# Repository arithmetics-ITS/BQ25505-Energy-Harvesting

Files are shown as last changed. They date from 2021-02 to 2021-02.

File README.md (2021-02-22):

# Breakout Board: BQ25505 ultra low-power energy harvester with battery management and autonomous power multiplexing
## Description

The bq25505 device is specifically designed to efficiently extract the microwatts (μW) to miliwatts (mW) of power generated from a variety of DC energy harvesting, high-impedance sources like photovoltaic (solar) or thermal electric generators (TEGs) without collapsing those sources. The batterymanagement features of the bq25505 ensure that a secondary rechargeable battery is not overcharged by this extracted power, with voltage boosted, nor depleted beyond safe limits by a system load. The
integrated multiplexer gate drivers autonomously switch the system load to a primary nonrechargeable battery if the secondary battery voltage falls below the user-defined VBAT_OK threshold.

## Features

- Texas Instruments BQ25505
- Designed for solar applications with MPPT
- 2x Dual, P-Channel, ChipFET 20 V, 4.1 A for primary and secondary battery switching
- 2x LEDs to visualize the currently used battery (PRI or SEC)

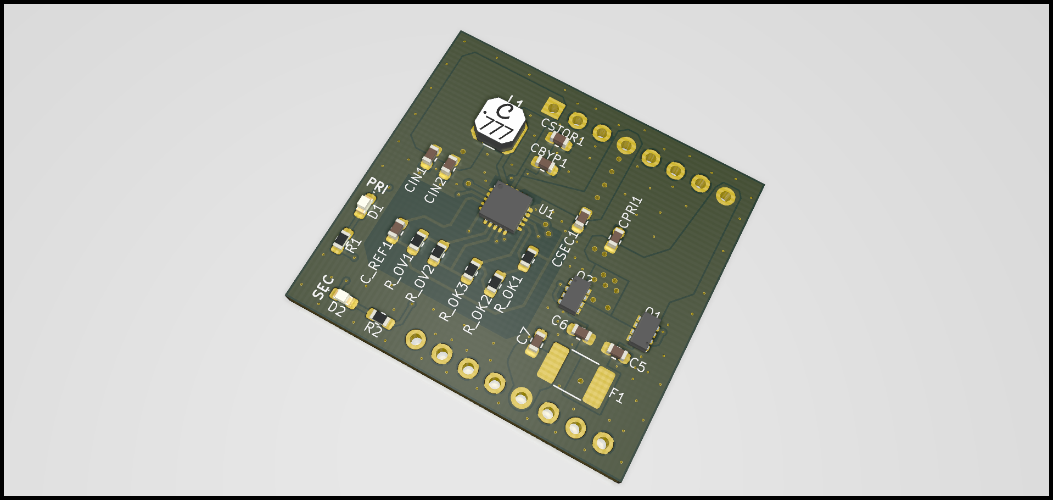
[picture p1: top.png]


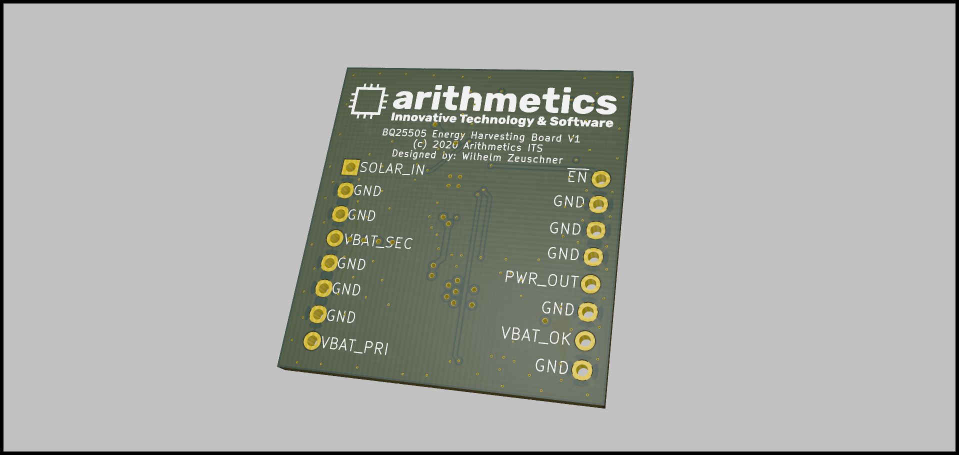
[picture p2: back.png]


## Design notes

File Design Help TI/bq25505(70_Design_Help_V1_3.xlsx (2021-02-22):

User Input | VBIAS | 1.21 | V
Fixed
 | Comparator threshold for VSTOR of charger. |  |  |  |  | Comparator threshold voltages indicating when |  |  |  |  | For the bq25570 only, comparator threshold |  |  |  |  | Maximum power point threshold, e.g. ~0.7-0.8 of
 | Typically the max storage element voltage, |  |  |  |  | VSTOR has risen above VBAT_OK_HYST or fallen |  |  |  |  | for VOUT of buck converter. |  |  |  |  | solar panel's open circuit voltage.
 | e.g. 4.2V for LiIon battery. |  |  |  |  | below VBAT_OK.
 | VBAT_UV < VBAT_OV < 5.5V |  |  |  |  | VBAT_OV > VBAT_OK_HYST > VBAT_UV |  |  |  |  | 1.3V < VOUT < VBAT_OV |  |  |  |  | MPPT
Desired |  |  |  |  |  | RSUM1 | 13 | MW |  |  |  |  |  |  |  | RSUM1 | 20 | MW
Desired | RSUM1 | 13 | MW |  |  | VBAT_OK | 2.8 | V | > VBAT_UV |  | RSUM1 | 13 | MW |  |  | VIN_DC(OC) | 1 | V | Open Circuit Volts
Desired | VBAT_OV | 4.2 | V |  |  | VBAT_OK_HYST | 3.1 | V | > VBAT_OK |  | VOUT | 1.3 | V |  |  | VREF_SAMP | 0.9 | V | MPP voltage
 |  |  |  |  |  |  |  | closest 1% resistor1 |  |  |  |  |  |  |  |  |  | closest 1% resistor1
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

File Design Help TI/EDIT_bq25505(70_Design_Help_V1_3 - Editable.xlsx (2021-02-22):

User Input | VBIAS | 1.21 | V |  |  |  |  |  |  |  | NICHT VERWENDET / BENÖTIGT |  |  |  |  | NICHT VERWENDET / BENÖTIGT
Fixed
 | Comparator threshold for VSTOR of charger. |  |  |  |  | Comparator threshold voltages indicating when |  |  |  |  | For the bq25570 only, comparator threshold |  |  |  |  | Maximum power point threshold, e.g. ~0.7-0.8 of
 | Typically the max storage element voltage, |  |  |  |  | VSTOR has risen above VBAT_OK_HYST or fallen |  |  |  |  | for VOUT of buck converter. |  |  |  |  | solar panel's open circuit voltage.
 | e.g. 4.2V for LiIon battery. |  |  |  |  | below VBAT_OK.
 | VBAT_UV < VBAT_OV < 5.5V |  |  |  |  | VBAT_OV > VBAT_OK_HYST > VBAT_UV |  |  |  |  | 1.3V < VOUT < VBAT_OV |  |  |  |  | MPPT
Desired |  |  |  |  |  | RSUM1 | 13 | MW |  |  |  |  |  |  |  | RSUM1 | 20 | MW
Desired | RSUM1 | 14 | MW |  |  | VBAT_OK | 2.5 | V | > VBAT_UV |  | RSUM1 | 13 | MW |  |  | VIN_DC(OC) | 1 | V | Open Circuit Volts
Desired | VBAT_OV | 4.1 | V |  |  | VBAT_OK_HYST | 2.7 | V | > VBAT_OK |  | VOUT | 1.3 | V |  |  | VREF_SAMP | 0.9 | V | MPP voltage
 |  |  |  |  |  |  |  | closest 1% resistor1 |  |  |  |  |  |  |  |  |  | closest 1% resistor1
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

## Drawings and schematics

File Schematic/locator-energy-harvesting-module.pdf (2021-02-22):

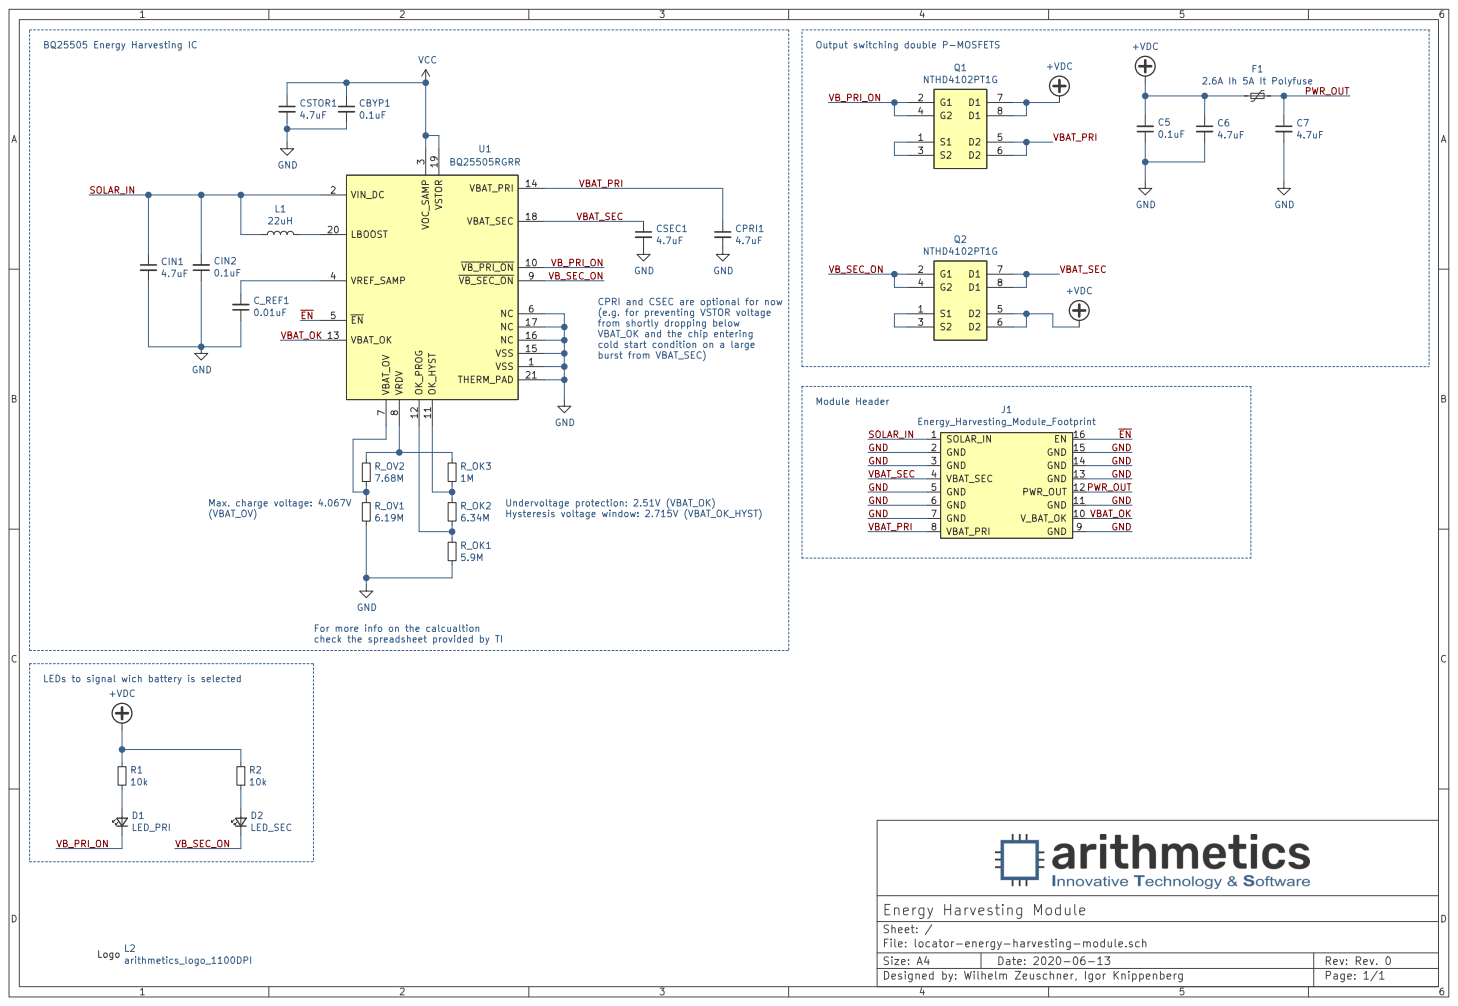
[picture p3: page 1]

Output switching double P-MOSFETS

CPRI and CSEC are optional for now
(e.g. for preventing VSTOR voltage
from shortly dropping below
VBAT_OK and the chip entering
cold start condition on a large
burst from VBAT_SEC)

check the spreadsheet provided by TI

Energy Harvesting Module
File: locator-energy-harvesting-module.sch Sheet: /

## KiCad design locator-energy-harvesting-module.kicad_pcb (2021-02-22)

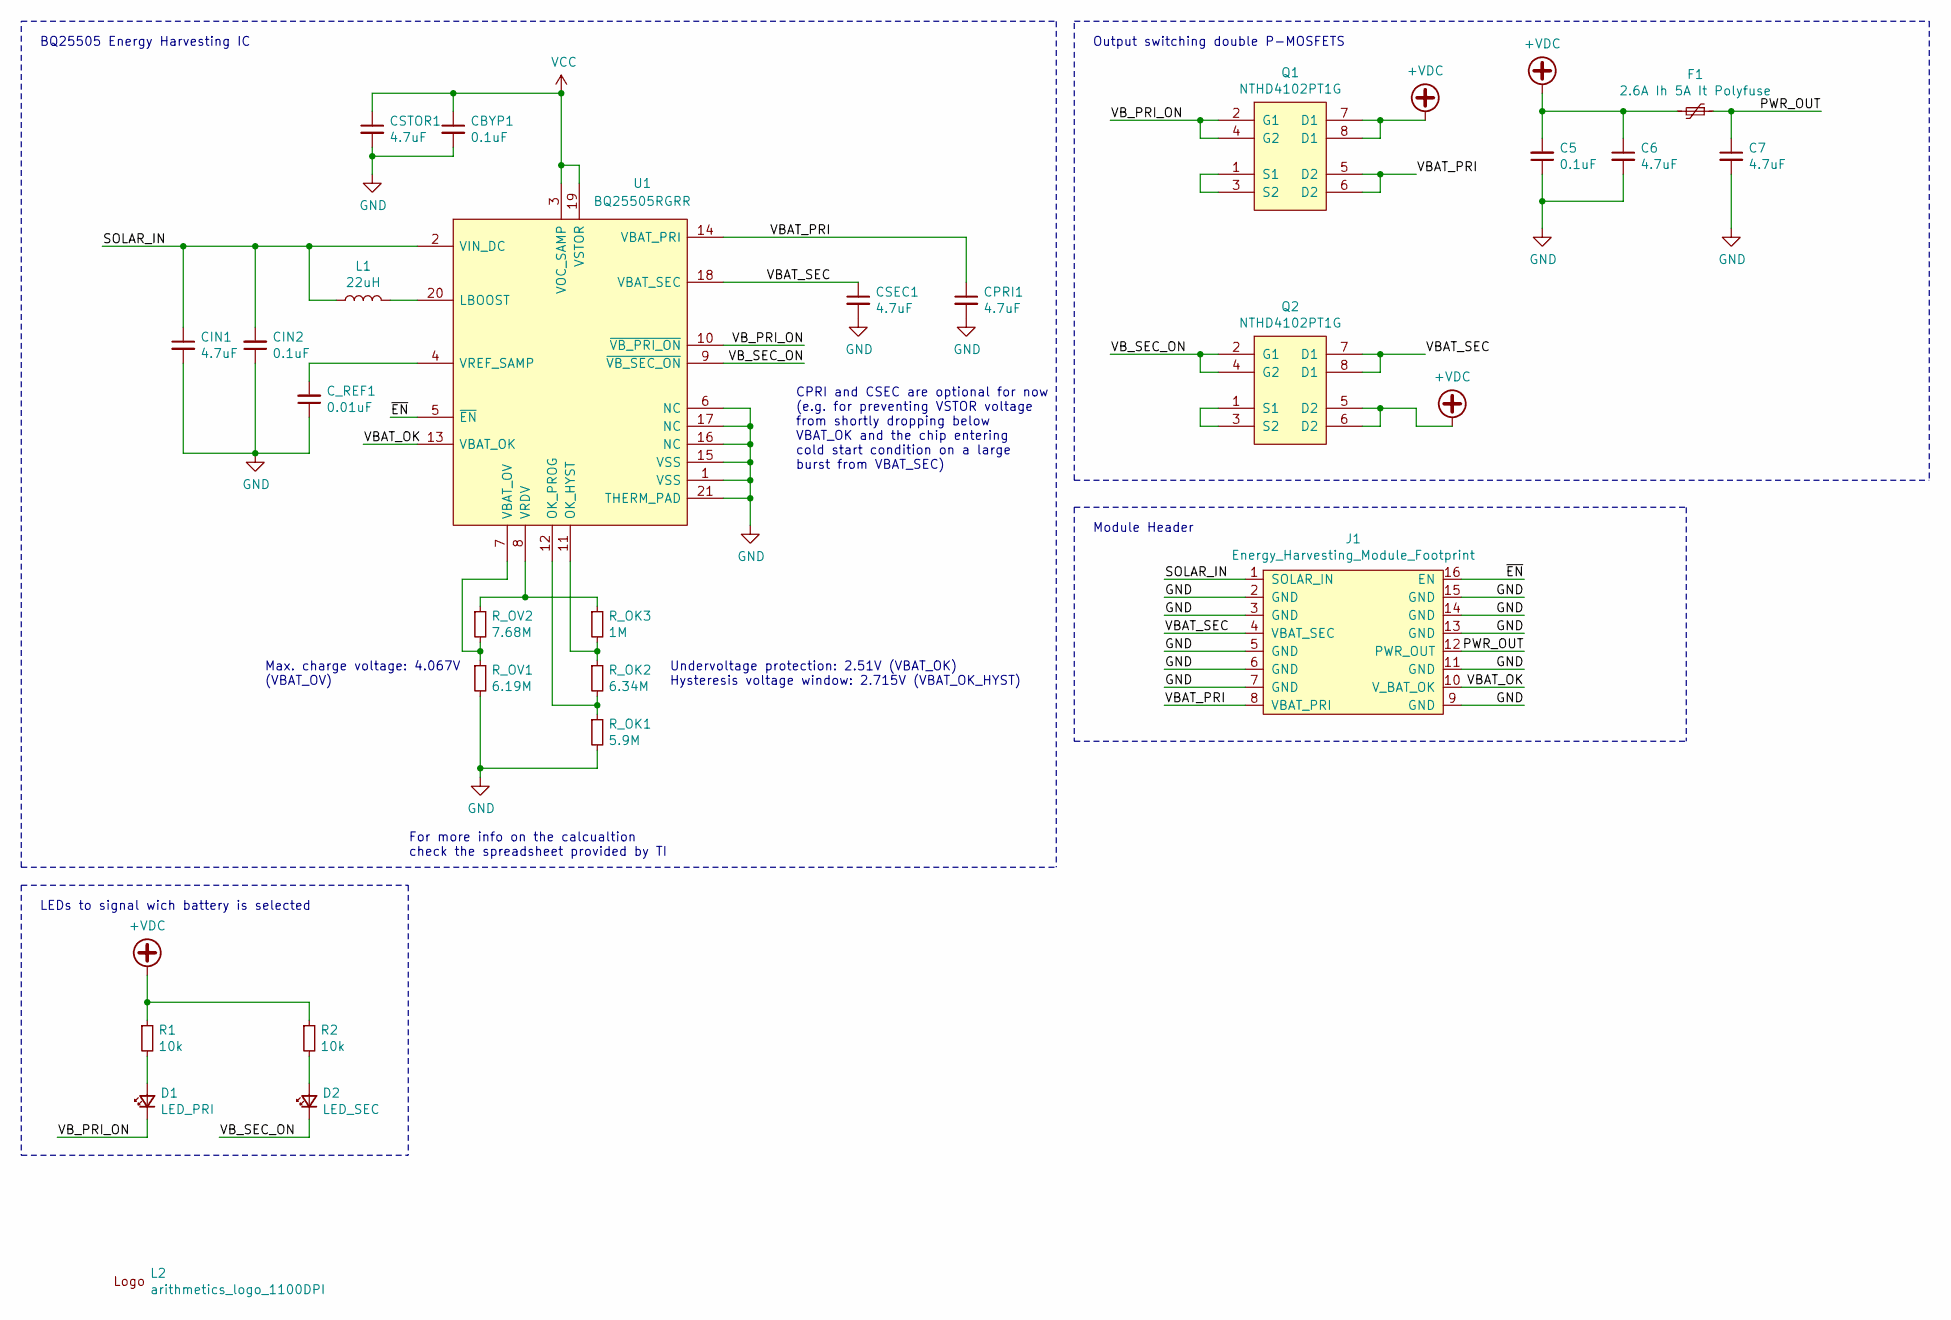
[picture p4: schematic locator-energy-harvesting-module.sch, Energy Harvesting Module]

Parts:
C5: 0.1uF; C_0603_1608Metric; MPN C0603X104J4RECAUTO
C6, C7: 4.7uF; C_0603_1608Metric; MPN C1608X5R1C475K080AC
CBYP1: 0.1uF; C_0603_1608Metric; MPN C0603X104J4RECAUTO
CIN1: 4.7uF; C_0603_1608Metric; MPN C1608X5R1C475K080AC
CIN2: 0.1uF; C_0603_1608Metric; MPN C0603X104J4RECAUTO
CPRI1: 4.7uF; C_0603_1608Metric; MPN C1608X5R1C475K080AC
CSEC1: 4.7uF; C_0603_1608Metric; MPN C1608X5R1C475K080AC
CSTOR1: 4.7uF; C_0603_1608Metric; MPN C1608X5R1C475K080AC
C_REF1: 0.01uF; C_0603_1608Metric; MPN GRM1885C1H103JA01D
D1: LED_PRI; LED_0603_1608Metric; MPN LS L29K-G1H2-1-Z
D2: LED_SEC; LED_0603_1608Metric; MPN LS L29K-G1H2-1-Z
F1: 2.6A Ih 5A It Polyfuse; Fuse_1812_4532Metric_Castellated; MPN 0ZCG0260FF2C
J1: Energy_Harvesting_Module_Footprint
L1: 22uH; L_Coilcraft_LPS4018; MPN LPS4018-223MRB
L2: arithmetics_logo_1100DPI; logo_1100_DPI
Q1, Q2: NTHD4102PT1G; NTHD4102P_ChipFET_CASE_1206A; MPN NTHD4102PT1G
R1, R2: 10k; R_0603_1608Metric; MPN AC0603JR-0710KL
R_OK1: 5.9M; R_0603_1608Metric; MPN CRCW06035M90FKEA
R_OK2: 6.34M; R_0603_1608Metric; MPN CRCW06036M34FKEA
R_OK3: 1M; R_0603_1608Metric; MPN AC0603FR-071ML
R_OV1: 6.19M; R_0603_1608Metric; MPN CRCW06036M19FKEA
R_OV2: 7.68M; R_0603_1608Metric; MPN CRCW06037M68FKEA
U1: BQ25505RGRR; BQ25505; MPN BQ25505RGRR

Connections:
+VDC: C5.2, C6.1, F1.2, Q1.7 (D1), Q1.8 (D1), Q2.5 (D2), Q2.6 (D2), R1.1, R2.1
/PWR_OUT: C7.1, F1.1, J1.12 (PWR_OUT)
/SOLAR_IN: CIN1.1, CIN2.2, J1.1 (SOLAR_IN), L1.1, U1.2 (VIN_DC)
/VBAT_OK: J1.10 (V_BAT_OK), U1.13 (VBAT_OK)
/VBAT_PRI: CPRI1.1, J1.8 (VBAT_PRI), Q1.5 (D2), Q1.6 (D2), U1.14 (VBAT_PRI)
/VBAT_SEC: CSEC1.1, J1.4 (VBAT_SEC), Q2.7 (D1), Q2.8 (D1), U1.18 (VBAT_SEC)
/VB_PRI_ON: D1.1 (K), Q1.2 (G1), Q1.4 (G2), U1.10 (~VB_PRI_ON)
/VB_SEC_ON: D2.1 (K), Q2.2 (G1), Q2.4 (G2), U1.9 (~VB_SEC_ON)
/~EN: J1.16 (EN), U1.5 (~EN)
GND: C5.1, C6.2, C7.2, CBYP1.2, CIN1.2, CIN2.1, CPRI1.2, CSEC1.2, CSTOR1.2, C_REF1.1, J1.2 (GND), J1.3 (GND), J1.5 (GND), J1.6 (GND), J1.7 (GND), J1.9 (GND), J1.11 (GND), J1.13 (GND), J1.14 (GND), J1.15 (GND), R_OK1.2, R_OV1.2, U1.1 (VSS), U1.6 (NC), U1.15 (VSS), U1.16 (NC), U1.17 (NC), U1.21 (THERM_PAD)
unnamed: C_REF1.2, U1.4 (VREF_SAMP)
unnamed: D1.2 (A), R1.2
unnamed: D2.2 (A), R2.2
unnamed: L1.2, U1.20 (LBOOST)
unnamed: Q1.1 (S1), Q1.3 (S2)
unnamed: Q2.1 (S1), Q2.3 (S2)
unnamed: R_OK1.1, R_OK2.2, U1.12 (OK_PROG)
unnamed: R_OK2.1, R_OK3.2, U1.11 (OK_HYST)
unnamed: R_OK3.1, R_OV2.1, U1.8 (VRDV)
unnamed: R_OV1.1, R_OV2.2, U1.7 (VBAT_OV)
VCC: CBYP1.1, CSTOR1.1, U1.3 (VOC_SAMP), U1.19 (VSTOR)

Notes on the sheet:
For more info on the calcualtion check the spreadsheet provided by TI
Module Header
Output switching double P-MOSFETS
BQ25505 Energy Harvesting IC
Max. charge voltage: 4.067V (VBAT_OV)
Undervoltage protection: 2.51V (VBAT_OK) Hysteresis voltage window: 2.715V (VBAT_OK_HYST)
CPRI and CSEC are optional for now (e.g. for preventing VSTOR voltage from shortly dropping below VBAT_OK and the chip entering cold start condition on a large burst from VBAT_SEC)
LEDs to signal wich battery is selected

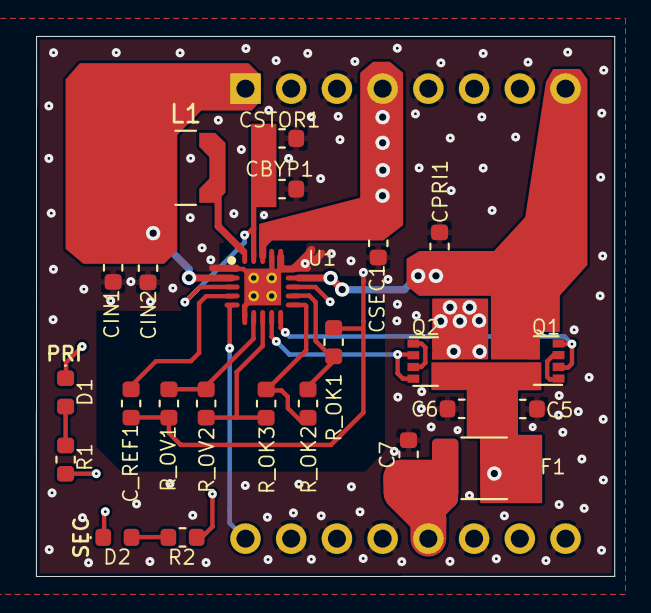
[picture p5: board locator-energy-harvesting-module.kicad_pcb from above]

Board: 4 copper layers, 32.1 x 30.0 mm, 26 parts (1 on the bottom side), 21 nets.

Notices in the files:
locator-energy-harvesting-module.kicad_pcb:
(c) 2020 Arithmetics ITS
